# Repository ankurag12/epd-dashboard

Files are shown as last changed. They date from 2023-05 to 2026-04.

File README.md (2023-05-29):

# stoic-dashboard

**Dashboard that displays a new Stoic thought everyday!**

<p align="middle">
  
   
</p>

The main components of the project are:

- [Plastic Logic's Electrophoretic Display (EPD)](https://www.plasticlogic.com/product/parrot-msp430-for-10-7-display/):
  Similar to an E-ink display; it's optimal for this application as it consumes energy only when the image is updated.
- [Adafruit HUZZAH32-ESP32](https://learn.adafruit.com/adafruit-huzzah32-esp32-feather): An ESP32 board. This runs the
  firmware for the dashboard in MicroPython, and provides functionality like connecting to a WiFi network, pulling image
  from the server, and sending it to the EPD controller.
- [ESP32-EPD Adapter](designs): The original eval-kit from Plastic Logic is powered by an MSP430 MCU. However, I wanted
  to run it using an ESP32 for features like WiFi connectivity and Python compatibility. So I made this adapter board
  that stacks on top of the Adafruit HUZZAH32-ESP32 and connects to the FPC that goes to the EPD controller board (Raven), replacing the MSP430 board (Parrot).
- [RaspberryPi](https://www.raspberrypi.com/products/raspberry-pi-4-model-b/): It acts as a server that runs 24x7,
  maintaining a repository of images by pulling from Instagram
  account [@dailystoic](https://www.instagram.com/dailystoic/) and serving it to ESP32.

Other accessories include

- 3.7V LiPo battery
- [FFC/FPC extenders](https://www.adafruit.com/search?q=0.5mm+FFC+%2F+FPC+Extender) + [Flex cables](https://www.amazon.com/dp/B00W8W9PZO)
  to make connecting different boards easier after framing
- Frame using [foam-board](https://www.michaels.com/product/20-x-30-white-foam-board-10110205)
  and [leather sheet](https://www.amazon.com/gp/product/B08XJW7ZDR) (because I didn't have access to woodworking tools!)

This repo contains the ESP32 firmware ([frontend](frontend)), RPi server code ([backend](backend)) and design files for
the ESP32-EPD adapter ([designs](designs)).

## backend

Run this code on a permanently powered and internet connected system like a RaspberryPi. If a RaspberryPi isn't
available, any computer running Python can be used as a server. Just make sure to update the URL
in [main.py](frontend/main.py).

To setup, create a Python venv and install dependencies

```commandline
cd backend
python -m venv .env
source ./.env/bin/activate
pip install -U pip
pip install -r requirements.txt
```

and run the server indefinitely.

```commandline
nohup python server.py &
```

After a few seconds, there should be images downloaded in `backend/image_repo`. You can verify that the server is
working well by visiting http://raspberrypi.local:8080 in your browser.

The server maintains a queue of available images from `image_repo`, popping one out whenever client (ESP32) queries. If
the size of the queue drops below a threshold (default=10), it executes another pull from Instagram to
update `image_repo` and the queue.

To avoid repeating images, it also maintains a history of previously served images as `history.pkl`. Delete that file to
recycle old images.

## frontend

This is a MicroPython port of the
original [MSP430 firmware from PlasticLogic](https://github.com/plasticlogic/pl-mcu-epd) (written in C) with some modifications like
pulling the image to display from a server on the network instead of reading from an SD-card.

If not done already, follow the steps here to
prepare [ESP32 for MicroPython](https://docs.micropython.org/en/latest/esp32/tutorial/intro.html).

Create a Python3.7 venv and install dependencies

```commandline
cd frontend
python3.7 -m venv .env
source ./.env/bin/activate
pip install -U pip
pip install -r requirements.txt
```

Change WiFi and SSID and password in [wifi.json](frontend/wifi.json), and run `run.sh`

```commandline
./run.sh
```

This will transfer all frontend code and configs to the ESP32, pull an image from the server, display it on the EPD, and
go to [deep sleep](https://lastminuteengineers.com/esp32-deep-sleep-wakeup-sources/) for approx 24 hours. On wake-up, it
will pull and display a new image.

Before running `run.sh`, make sure that the server is running, else the frontend code will crash because
it can't find server! If that happens, perform a hard reset

```commandline
ampy --port /dev/cu.SLAB_USBtoUART reset --hard
```

#### Changing an image on demand

If you want to change the current image (and understandably don't want to wait 24 hours), ESP32 has a way to wake-up
from deep sleep
using [touch](https://docs.micropython.org/en/latest/esp32/quickref.html?highlight=deep_sleep#capacitive-touch). ESP32
has several capacitive touch-enabled pins; I'm using GPIO #14 that I fly-wired to a corner of the dashboard. Touching
that corner wakes up the ESP32 and updates the image. It could take ~20s, but still pretty cool! 

## designs
I used KiCad for designing the adapter board.

## Why Stoic?
Because I find it interesting 🤷

But yeah, technically, it's a generic dashboard, and one can add any number of Instagram accounts as `SOURCES` in [server.py](backend/server.py) :)

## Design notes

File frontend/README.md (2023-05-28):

This MicroPython code runs on the ESP32 hardware. Specific board used was [Adafruit HUZZAH32-ESP32](https://learn.adafruit.com/adafruit-huzzah32-esp32-feather)

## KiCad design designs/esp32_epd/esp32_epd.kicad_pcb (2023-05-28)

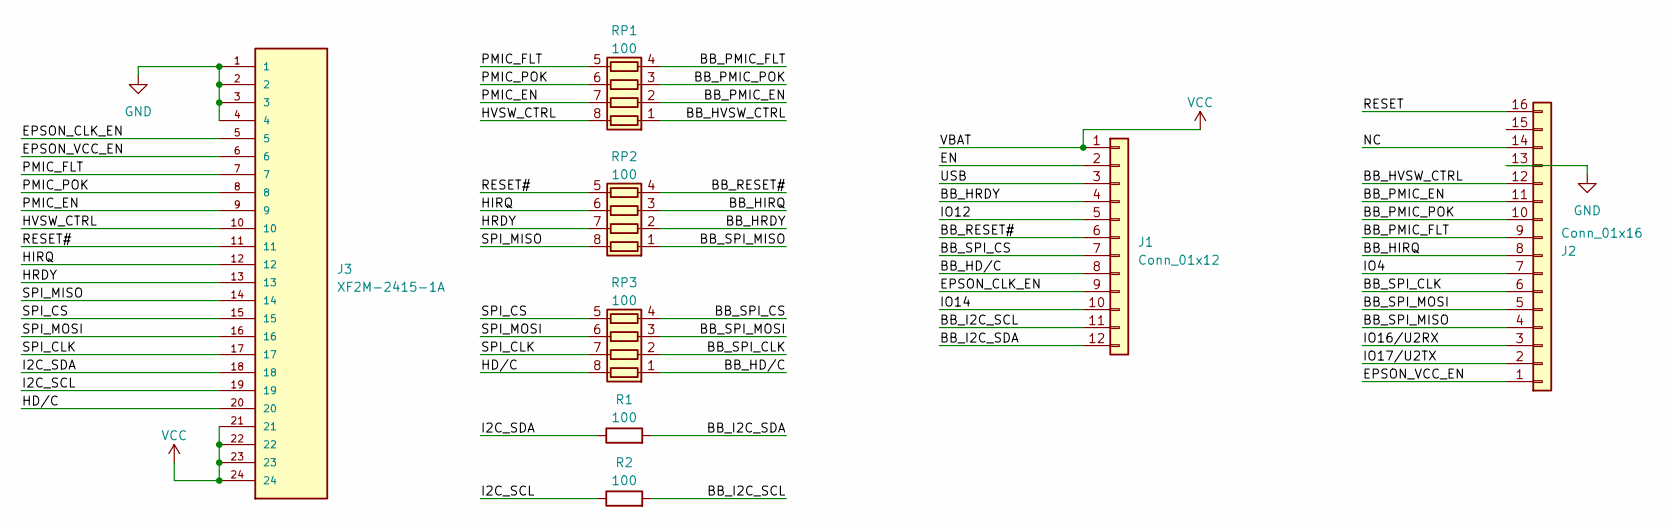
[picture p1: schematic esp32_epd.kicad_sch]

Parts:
J1: Conn_01x12; PinHeader_1x12_P2.54mm_Vertical
J2: Conn_01x16; PinHeader_1x16_P2.54mm_Vertical
J3: XF2M-2415-1A; OMRON_XF2M-2415-1A
R1, R2: 100; R_0603_1608Metric_Pad0.98x0.95mm_HandSolder
RP1, RP2, RP3: 100; RESCAXE80P320X160X70-8N

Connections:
/BB_HD/C: J1.8, RP3.1 (R1.1)
/BB_HIRQ: J2.8, RP2.3 (R3.1)
/BB_HRDY: J1.4, RP2.2 (R2.1)
/BB_HVSW_CTRL: J2.12, RP1.1 (R1.1)
/BB_I2C_SCL: J1.11, R2.2
/BB_I2C_SDA: J1.12, R1.2
/BB_PMIC_EN: J2.11, RP1.2 (R2.1)
/BB_PMIC_FLT: J2.9, RP1.4 (R4.1)
/BB_PMIC_POK: J2.10, RP1.3 (R3.1)
/BB_RESET#: J1.6, RP2.4 (R4.1)
/BB_SPI_CLK: J2.6, RP3.2 (R2.1)
/BB_SPI_CS: J1.7, RP3.4 (R4.1)
/BB_SPI_MISO: J2.4, RP2.1 (R1.1)
/BB_SPI_MOSI: J2.5, RP3.3 (R3.1)
/EN: J1.2
/EPSON_CLK_EN: J1.9, J3.5
/EPSON_VCC_EN: J2.1, J3.6
/HD/C: J3.20, RP3.8 (R1.2)
/HIRQ: J3.12, RP2.6 (R3.2)
/HRDY: J3.13, RP2.7 (R2.2)
/HVSW_CTRL: J3.10, RP1.8 (R1.2)
/I2C_SCL: J3.19, R2.1
/I2C_SDA: J3.18, R1.1
/IO4: J2.7
/IO12: J1.5
/IO14: J1.10
/IO16/U2RX: J2.3
/IO17/U2TX: J2.2
/NC: J2.14
/PMIC_EN: J3.9, RP1.7 (R2.2)
/PMIC_FLT: J3.7, RP1.5 (R4.2)
/PMIC_POK: J3.8, RP1.6 (R3.2)
/RESET: J2.16
/RESET#: J3.11, RP2.5 (R4.2)
/SPI_CLK: J3.17, RP3.7 (R2.2)
/SPI_CS: J3.15, RP3.5 (R4.2)
/SPI_MISO: J3.14, RP2.8 (R1.2)
/SPI_MOSI: J3.16, RP3.6 (R3.2)
/USB: J1.3
GND: J2.13, J3.1, J3.2, J3.3, J3.4
VCC: J1.1, J3.21, J3.22, J3.23, J3.24

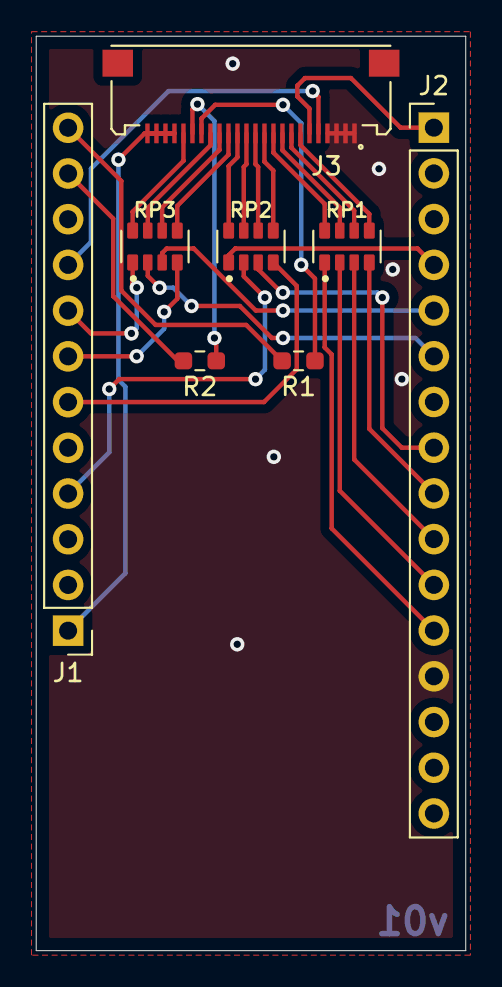
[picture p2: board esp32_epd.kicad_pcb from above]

Board: 2 copper layers, 23.9 x 50.8 mm, 8 parts (0 on the bottom side), 32 nets.

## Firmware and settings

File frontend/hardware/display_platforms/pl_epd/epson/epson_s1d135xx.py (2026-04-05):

import struct
from utils.logging import Logger
from utils.misc import ImageFile
import os

logger = Logger(__name__)


class S1D135xx:
    TEMP_MASK = 0x00FF

    DATA_BUFFER_LENGTH = 2048

    XMASK = 0x0FFF
    YMASK = 0x0FFF
    INIT_CODE_CHECKSUM_OK = (1 << 15)
    PWR_CTRL_UP = 0x8001
    PWR_CTRL_DOWN = 0x8002
    PWR_CTRL_BUSY = 0x0080
    PWR_CTRL_CHECK_ON = 0x2200

    class Register:
        REV_CODE = 0x0002
        SOFTWARE_RESET = 0x0008
        SYSTEM_STATUS = 0x000A
        I2C_CLOCK = 0x001A
        PERIPH_CONFIG = 0x0020
        HOST_MEM_PORT = 0x0154
        I2C_TEMP_SENSOR_VALUE = 0x0216
        I2C_STATUS = 0x0218
        PWR_CTRL = 0x0230
        SEQ_AUTOBOOT_CMD = 0x02A8
        DISPLAY_BUSY = 0x0338
        INT_RAW_STAT = 0x033A

    RotMode = {
        0: 0,
        90: 1,
        180: 2,
        270: 3
    }

    class CMD:
        INIT_SET = 0x00
        RUN = 0x02
        STBY = 0x04
        SLEEP = 0x05
        INIT_STBY = 0x06
        INIT_ROT_MODE = 0x0B
        READ_REG = 0x10
        WRITE_REG = 0x11
        BST_RD_SDR = 0x1C
        BST_WR_SDR = 0x1D
        BST_END_SDR = 0x1E
        LD_IMG = 0x20
        LD_IMG_AREA = 0x22
        LD_IMG_END = 0x23
        WAIT_DSPE_TRG = 0x28
        WAIT_DSPE_FREND = 0x29
        UPD_INIT = 0x32
        UPDATE_FULL = 0x33
        UPDATE_FULL_AREA = 0x34
        EPD_GDRV_CLR = 0x37

    def __init__(self, mcu, wflib_file=None):
        self._wflib = wflib_file
        self._mcu = mcu
        self._spi = mcu.spi["EPSON"]
        self._hdc = mcu.gpio.get("EPSON_HDC")
        self._hrdy = None   # the demo C code has "#define SPI_HRDY_USED     0 "
        self._cs = mcu.gpio.get("CS_0")
        self._reset = mcu.gpio.get("RESET")
        self._clk_en = mcu.gpio.get("CLK_EN")
        self._vcc_en = mcu.gpio.get("VCC_EN")
        self._hrdy_mask = None
        self._hrdy_result = None
        self.xres = None
        self.yres = None
        self._measured_temp = None
        self._init_code_file = f"{os.getcwd()}hardware/display_platforms/pl_epd/epson/bin/Ecode.bin"
        self._flags_needs_update = 0
        self._temp_mode = None
        self._manual_temp = 0

        if self._hrdy:
            logger.info("Using HRDY GPIO")
        if self._hdc:
            logger.info("Using HDC GPIO")

    def _get_hrdy(self):
        if self._hrdy:
            return self._hrdy.get_pin()
        status = self._read_reg(S1D135xx.Register.SYSTEM_STATUS)
        return (status & self._hrdy_mask) == self._hrdy_result

    def _do_fill(self, area, bpp, g):
        if bpp == 4:
            val16 = g & 0xF0
            val16 |= val16 >> 4
            val16 |= val16 << 8
            pixels = area["width"] // 4
        elif bpp == 8:
            val16 = g | (g << 8)
            pixels = area["width"] // 2
        else:
            raise ValueError(f"Unsupported bpp {bpp}")

        lines = area["height"]

        self._wait_idle()

        self._set_cs(0)
        self._send_cmd(S1D135xx.CMD.WRITE_REG)
        self._send_param(S1D135xx.Register.HOST_MEM_PORT)

        while lines:
            self._send_params([val16] * pixels)
            lines -= 1
        logger.info(f"Filled all")

        self._set_cs(1)
        self._wait_idle()
        self._send_cmd_cs(S1D135xx.CMD.LD_IMG_END)
        self._wait_idle()

    def _wflib_wr(self, data):
        self._set_cs(0)
        self._send_cmd(S1D135xx.CMD.WRITE_REG)
        self._send_param(S1D135xx.Register.HOST_MEM_PORT)
        self._transfer_data(data)
        self._set_cs(1)

    def _transfer_file(self, file):
        chunk = file.read(S1D135xx.DATA_BUFFER_LENGTH)
        while chunk:
            self._transfer_data(chunk)
            chunk = file.read(S1D135xx.DATA_BUFFER_LENGTH)

    def _transfer_image(self, file, area, left, top, width):
        if width < area["width"] or width < (left + area["width"]):
            raise ValueError("Invalid combination of width/left/area")

        # First ignore the top cropped area
        file.seek(file.tell() + top * width)

        for line in range(area["height"] - 1, -1, -1):
            remaining = area["width"]

            # Find the first relevant pixel (byte) on this line
            file.seek(left + file.tell())

            # Transfer data of interest in chunks
            while remaining:
                read_count = min(remaining, S1D135xx.DATA_BUFFER_LENGTH)
                chunk = file.read(read_count)
                self._transfer_data(chunk)
                remaining -= read_count

            # Move file pointer to end of line
            file.seek(file.tell() + width - (left + area["width"]))

    def _transfer_data(self, data):
        # Data is a byte array in little endian. Target wants word array in big endian
        data = struct.pack(f"<{len(data) // 2}H", *struct.unpack(f">{len(data) // 2}H", data))
        self._spi.write_bytes(data)

    def _send_cmd_area(self, cmd, mode, area):
        args = [
            mode,
            area["left"] & S1D135xx.XMASK,
            area["top"] & S1D135xx.YMASK,
            area["width"] & S1D135xx.XMASK,
            area["height"] & S1D135xx.YMASK
        ]
        self._send_cmd(cmd)
        self._send_params(args)

    def _send_cmd_cs(self, cmd):
        self._set_cs(0)
        self._send_cmd(cmd)
        self._set_cs(1)

    def _send_cmd(self, cmd):
        cmd = cmd.to_bytes(2, "big")
        self._set_hdc(0)
        self._spi.write_bytes(cmd)
        self._set_hdc(1)

    def _send_params(self, params):
        params = b''.join([param.to_bytes(2, "big") for param in params])
        self._spi.write_bytes(params)

    def _send_param(self, param):
        # param is an integer
        param = param.to_bytes(2, "big")
        self._spi.write_bytes(param)

    def _set_cs(self, state):
        self._cs.set_pin(state)

    def _set_hdc(self, state):
        if self._hdc:
            self._hdc.set_pin(state)

    @classmethod
    def _wf_mode(cls, wf):
        return (wf << 8) & 0x0F00

    def _wait_idle(self, timeout_ms=5000):
        start = self._mcu.ticks_ms()
        while not self._get_hrdy():
            if self._mcu.ticks_diff(self._mcu.ticks_ms(), start) > timeout_ms:
                raise RuntimeError(f"HRDY timeout")
            self._mcu.sleep_ms(1)

    def _early_init(self):
        raise

    def _hard_reset(self):
        if not self._reset:
            logger.warning(f"No Hard Reset")
            return
        self._reset.set_pin(0)
        self._mcu.sleep_ms(4)
        self._reset.set_pin(1)
        self._mcu.sleep_ms(10)

    def _soft_reset(self):
        self._write_reg(S1D135xx.Register.SOFTWARE_RESET, 0xFF)
        self._wait_idle()

    def _check_prod_code(self, ref_code):
        prod_code = self._read_reg(S1D135xx.Register.REV_CODE)
        logger.info(f"Product code : {prod_code}")

        if prod_code != ref_code:
            raise ValueError(f"Invalid product code, expected {ref_code}, got {prod_code}")
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

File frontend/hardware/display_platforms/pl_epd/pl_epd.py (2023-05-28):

from hardware.display_platforms.common import DisplayPlatform
from utils.logging import Logger
from hardware.display_platforms.pl_epd.pl.epdpsu import EpdPsuGPIO, EpdPsuEPDC
from hardware.display_platforms.pl_epd.pmic.max17135 import Max17135
from hardware.display_platforms.pl_epd.epson.epson_s1d13524 import S1D13524
import os

logger = Logger(__name__)


class PlEpd(DisplayPlatform):
    _HW_INFO_DEFAULT = {
        "version": 1,
        "vcom": {
            "dac_x1": 63,
            "dac_y1": 4586,
            "dac_x2": 189,
            "dac_y2": 9800,
            "vgpos_mv": 27770,
            "vgneg_mv": -41520,
            "swing_ideal": 70000},
        "board": {
            "board_type": "Raven",
            "board_ver_maj": 1,
            "board_ver_min": 0,
            "vcom_mode": 0,
            "hv_pmic": "HV_PMIC_MAX17135",
            "vcom_dac": 0,
            "vcom_adc": 0,
            "io_config": 0,
            "i2_mode": "CONFIG_DEFAULT_I2C_MODE",
            "temp_sensor": "TEMP_SENSOR_LM75",
            "frame_buffer": 0,
            "epdc_ref": "EPDC_S1D13524",
            "adc_scale_1": 1,
            "adc_scale_2": 1
        },
        "crc": 0xFFFF
    }

    _DISP_INFO_DEFAULT = {
        "vermagic": {
            "magic": 0x46574C50,
            "version": 1
        },
        "info": {
            "panel_id": "",
            "panel_type": "Type11",
            "vcom": 3983,
            "waveform_md5": bytearray(b'\xFF' * 16),
            "waveform_full_length": 0,
            "waveform_lzss_length": 0,
            "waveform_id": "",
            "waveform_target": ""
        },
        "info_crc": 0xFFFF
    }

    # This covers all the "probe" calls in main.c
    def __init__(self, mcu, hw_info=None, disp_info=None, wflib_file=None):
        super().__init__(mcu=mcu)

        if not hw_info:
            hw_info = PlEpd._HW_INFO_DEFAULT

        if not disp_info:
            disp_info = PlEpd._DISP_INFO_DEFAULT

        if not wflib_file:
            wflib_file = f"{os.getcwd()}hardware/display_platforms/pl_epd/waveform.wbf"
        self._wflib_file = wflib_file

        self._hw_info = hw_info
        self._disp_info = disp_info

        self._init_pmic()
        self._init_epdc()
        self._init_psu()

    def _init_pmic(self):
        if self._hw_info["board"]["hv_pmic"] == "HV_PMIC_MAX17135":
            self._pmic = Max17135(self._mcu.i2c["EPSON"])
            vcom_cal = Max17135.vcom_init(self._hw_info["vcom"])
            self._pmic.configure(vcom_cal=vcom_cal, power_sequence=1)
            self._pmic.set_vcom_voltage(self._disp_info["info"]["vcom"])

        elif self._hw_info["board"]["hv_pmic"] == "HV_PMIC_TPS65185":
            raise NotImplementedError

        else:
            raise ValueError(f"Invalid HV-PMIC id : {self._hw_info['board']['hv_pmic']}")

    def _init_psu(self):
        if self._hw_info["board"]["board_type"] == "Raven":
            self._psu = EpdPsuEPDC(self._epdc)
        else:
            self._psu = EpdPsuGPIO(self._mcu)
        logger.info(f"Initialized EPD PSU", to_file=True)

    def _init_epdc(self):
        if self._hw_info["board"]["epdc_ref"] == "EPDC_S1D13524":
            self._epdc = S1D13524(self._mcu, wflib_file=self._wflib_file)
        else:
            raise NotImplementedError

        logger.info("Loading wflib")
        self._epdc.load_wflib()

        logger.info(f"Ready {self._epdc.xres}x{self._epdc.yres}")

        logger.info(f"Initialized EPDC", to_file=True)

    def show_image(self, img_path, area=None, left=0, top=0):
        self._epdc.load_image(img_path, area=area, left=left, top=top)
        self._epdc.update_temp()
        self._psu.on()
        self._epdc.update("refresh", area=area)
        self._epdc.wait_update_end()
        self._psu.off()

    def clear(self):
        logger.info(f"Clearing the screen")
        self._epdc.fill(None, 255)
        self._epdc.clear_init()
        self._psu.on()
        self._epdc.update("init", area=None)
        self._epdc.wait_update_end()
        self._psu.off()

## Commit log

2023-01-03 Add micropython blinky for esp32
2023-01-16 Packet-like data comm b/w MSP430 and ESP32
2023-01-29 Implement SPI
2023-03-06 Fix runtime bugs, clear display successfully
    [epson_s1d13524.py, epson_s1d135xx.py, esp32_upython.py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]
2023-03-27 Add PCB schematic and layout for ESP32-EPD adapter
    [esp32_epd.kicad_pcb, esp32_epd.kicad_sch]
2023-05-17 Clear screen on hard reset, log in txt file
    [esp32_upython.py, mcu.py]
2023-05-28 Fix PCB sch and layout with VCC->VBAT
    [esp32_epd.kicad_pcb, esp32_epd.kicad_sch]
